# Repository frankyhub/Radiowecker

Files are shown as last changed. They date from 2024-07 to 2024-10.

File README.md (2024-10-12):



<div align="center">

|[:skull:ISSUE](https://github.com/frankyhub/Radiowecker/issues?q=is%3Aissue)|[:speech_balloon: Forum /Discussion](https://github.com/frankyhub/Radiowecker/discussions)|[:grey_question:WiKi](https://github.com/frankyhub/Radiowecker/wiki)||
|--|--|--|--|
| | | | |
||<a href="https://github.com/frankyhub/Radiowecker/issues">|<a href="https://github.com/frankyhub/Radiowecker/discussions">|<a href="https://github.com/frankyhub/Radiowecker/releases">|
|| <a href="https://github.com/frankyhub/Radiowecker/pulse" alt="Activity">| <a href="https://github.com/frankyhub/Radiowecker/graphs/traffic">  |<a href="https://github.com/frankyhub?tab=stars"> |
</div>

Nach einer Idee und Vorlage von https://www.az-delivery.de/blogs/azdelivery-blog-fur-arduino-und-raspberry-pi/internet-radiowecker-mit-touchscreen.

# Radiowecker
Bedienung über 2,8" Touchscreen und WEB-Server, 3W Klasse D Amplifier

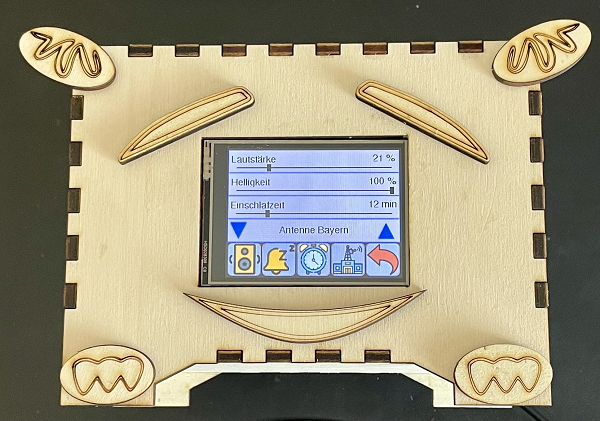
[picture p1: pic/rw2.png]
 

## Story
Das Repo beschreibt einen Radiowecker mit TFT-Display und WEB-Server. Zwei Weckzeiten können an beliebigen Wochentagen zugeordnet werden. Es ist auch ein Einschlaf-Timer vorhanden. Mit dem LDR kann man die Display-Helligkeit automatisch an die Raumhelligkeit anpassen. Über den Touchscreen sind Radio ein/aus, Einschlaftimer mit Einschlafzeit, Wecker ein/aus, Senderauswahl und Lautstärke einstellbar. Die Weckzeiten und die Stream-URLs der Radiostationen werden über ein Web-Interface konfiguriert.

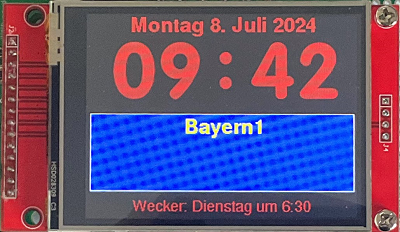
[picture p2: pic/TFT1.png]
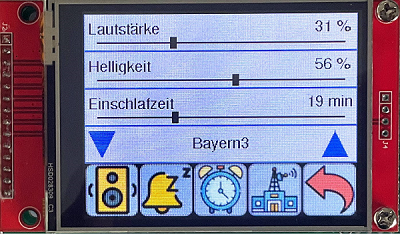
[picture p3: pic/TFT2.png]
 

## Inbetriebnahme

### Verdrahtung 

| TFT-Display | ESP32 | 
| --- | --- |
|  VCC  |  3,3V  |
|  GND | GDN |
| CS  | GPIO5  |
| RESET  | GPIO22 |
| DC | NC  |
| SDI  | GPIO23 |
| SCK  |  GPIO18  |
|  LED |  GPIO15  |
|  MISO | GPIO19 | 
| T-CLK  | GPIO18 | 
| T-CS  | GPIO14  | 
| T-DIN  | GPIO23  | 
| T-DO  | GPIO19  | 
| T-IRQ  | GPIO27  | 
|  --- |  --- | 

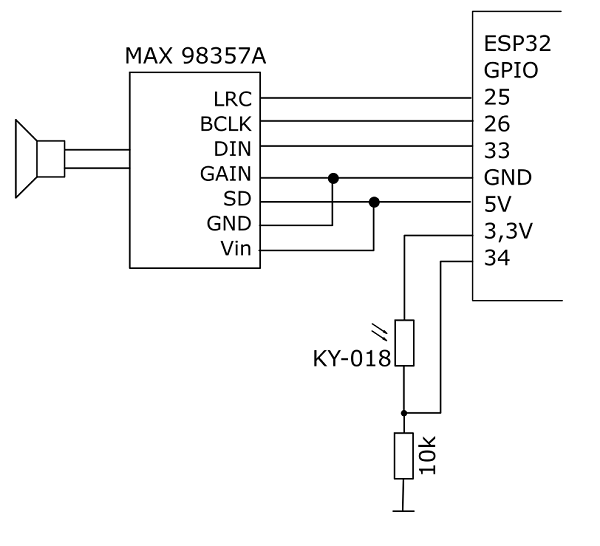
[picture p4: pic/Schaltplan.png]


### ESP32 TFT 2.8" Shield

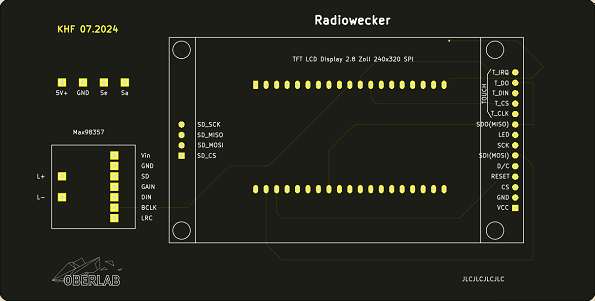
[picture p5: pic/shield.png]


### Gehäuse

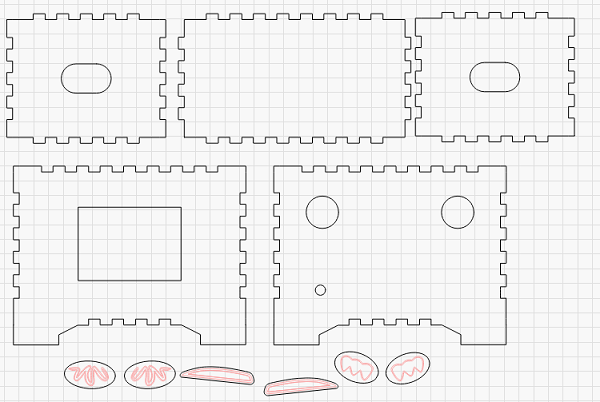
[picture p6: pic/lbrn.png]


### Nach anlegen der Versorgungsspannung startet der Accesspoit. In den Einstellungen des Handys oder Tablets wird das WLAN "Radiowecker" ausgewählt 

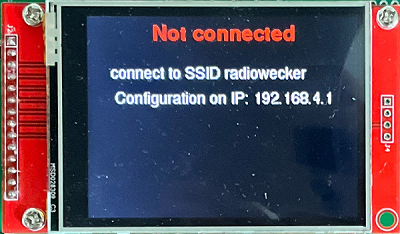
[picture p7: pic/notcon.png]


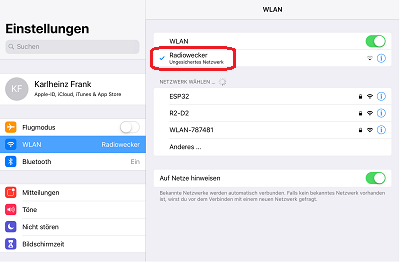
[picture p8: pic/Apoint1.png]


### und über einen Browser die URL 192.168.4.1 eingegeben und der Neustart-Button betätigt.

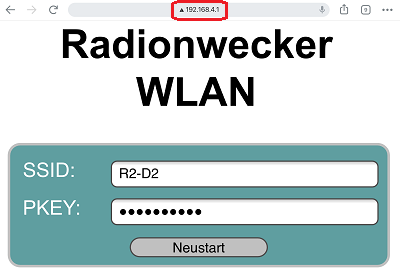
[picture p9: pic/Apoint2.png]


### Am Seriellen Monitor kann der Startvorgang beobachtet und die IP-Adresse des WEB-Servers abgelesen werden.

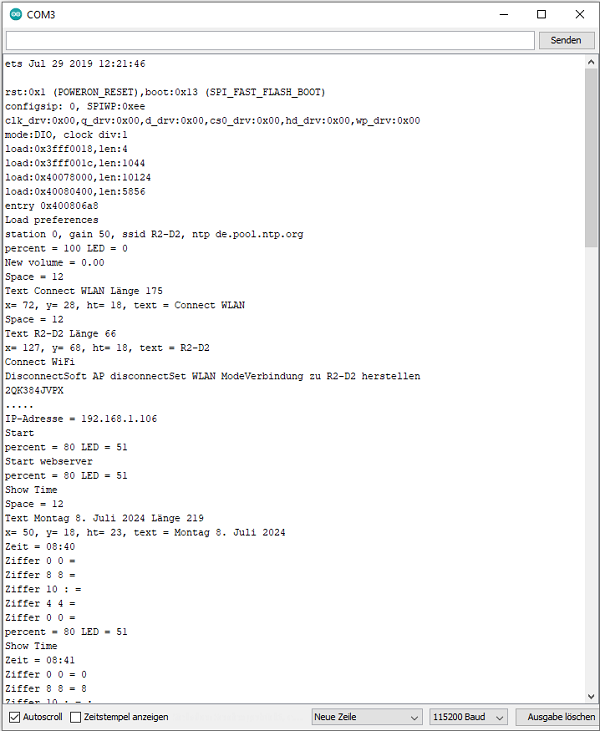
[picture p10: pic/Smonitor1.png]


### Am Display wird beim Startvorgang die WLAN-Verbindung angezeigt.

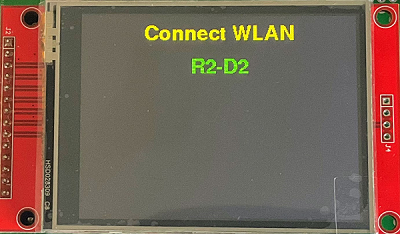
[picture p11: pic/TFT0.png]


### Nach dem Aufruf des WEB-Server sieht man die Einstellungen und passt diese an.

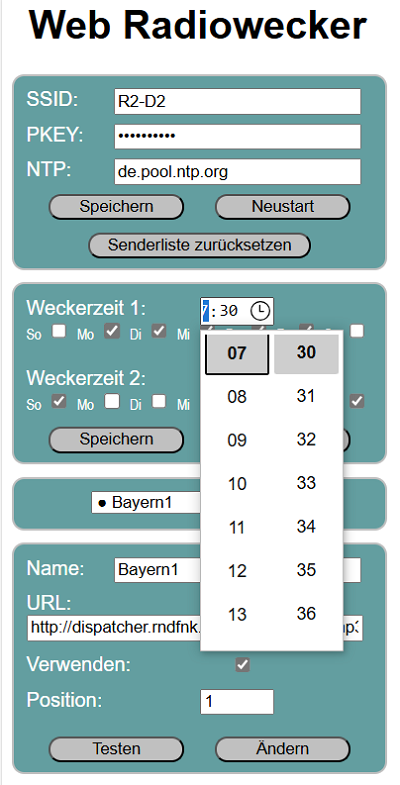
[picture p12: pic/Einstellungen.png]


### Die Bedienung kann auch über das TFT-Display erfolgen.

Bild

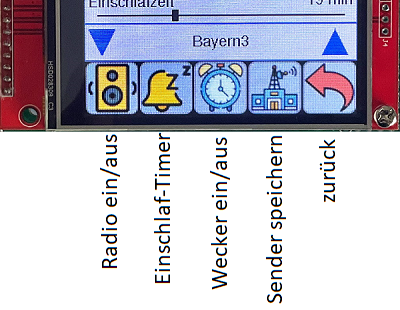
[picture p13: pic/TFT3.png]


## Bedienung

### Radio ein/aus
Das Radio wird ein- oder ausgeschaltet. Die Anzeige kehrt zur Zeitanzeige zurück. Wurde das Radio eingeschaltet, erscheint unter der Zeitanzeige der Radioblock mit dem Sendernamen.

### Einschlaftimer
Die Einschlafzeit wird gestartet. Falls das Radio nicht eingeschaltet ist, wird es eingeschaltet. Die Anzeige kehrt zur Zeitanzeige zurück. Wenn die eingestellte Einschlafzeit vorüber ist, wird das Radio automatisch ausgeschaltet.

### Wecker ein/aus
Die Wecker-Funktion wird ein- oder ausgeschaltet. Die Anzeige kehrt zur Zeitanzeige zurück. Wurde der Wecker eingeschaltet, erscheint ganz unten im Display der Wochentag und die Uhrzeit, wann der Wecker das nächste Mal ausgelöst wird. Wenn der angezeigte Wochentag und die Uhrzeit zutreffen, wird das Radio automatisch eingeschaltet.

### Sender speichern
Der ausgewählte Sender wird als aktiver Sender übernommen. Ist das Radio gerade eingeschaltet, so wechselt der Stream automatisch auf den neuen Sender. Die Anzeige kehrt zur Zeitanzeige zurück.

### Zurück
Die Anzeige kehrt zur Zeitanzeige zurück.

Erfolgt 10 Sekunden keine Aktivität, so kehrt die Anzeige automatisch zur Zeitanzeige zurück. Alle Einstellungsänderungen werden in den Präferenzen gespeichert. Die Bedienungsseite wird immer mit voller Helligkeit dargestellt.

Bild

## Konfiguration

### Über die URL http://radiowecker/ sollte die Konfigurationsseite abrufbar sein. 

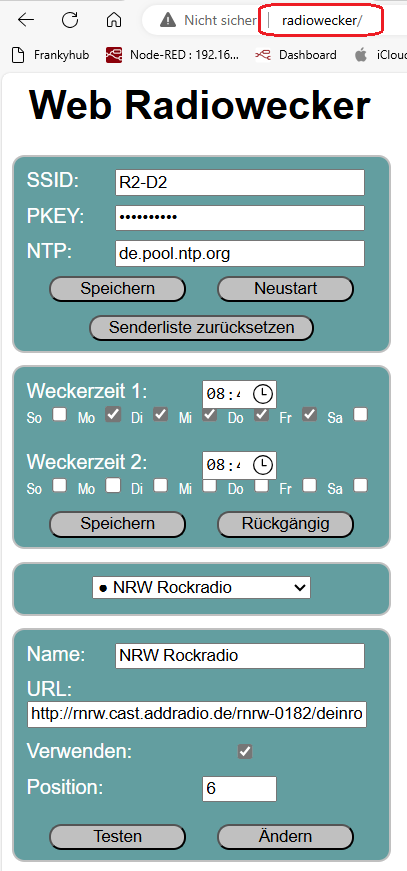
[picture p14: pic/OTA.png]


Im oberen Teil sieht man die WLAN-Zugangsdaten und den NTP-Server. Mit dem "Speichern-Button" werden Änderungen wirksam. Auch ein Neustart ist möglich. Als Nächstes folgen die Weckzeiten. Zwei Weckzeiten sind möglich. Für jede der Weckzeiten sind die Wochentage wählbar, an denen die Weckzeiten anzuwenden sind. Die Dropdown-Liste darunter enthält alle Sender der Senderliste. Auswählbare Sender haben vor dem Namen einen schwarzen Punkt. Im Formular darunter werden die Daten zur ausgewählten Station angezeigt und können geändert werden. Ist das Häkchen bei „Verwenden“ nicht gesetzt, ist die Station im Gerät nicht aktiv. Da manche URLs nicht funktionieren, sollte man eine neue URL erstmal testen. Ein Klicken auf den "Testen-Button" startet die Wiedergabe der URL am eingeschalteten Gerät. Sollte die Wiedergabe nicht funktionieren, wird wieder auf den aktuellen Sender zurückgeschaltet und eine Meldung angezeigt. Ist die Wiedergabe möglich, wird eine Box mit einem Knopf angezeigt. Klicken auf diesen Knopf schließt die Box und beendet den Test. Es wird wieder die aktuelle Station wiedergegeben. Im Eingabefeld „Position“ wird die Position der ausgewählten Station innerhalb der Senderliste angezeigt. Durch eine Änderung dieses Wertes, kann die Station auf die angegebene Position verschoben und mit dem Knopf „Ändern“ können die Änderungen für die ausgewählte Station dauerhaft geändert werden.

---

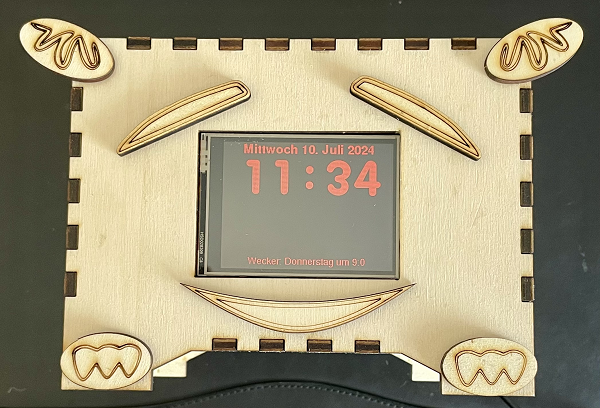
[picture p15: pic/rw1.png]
 

---

<div style="position:absolute; left:2cm; "> <ol class="breadcrumb" style="border-top: 2px solid black;border-bottom:2px solid black; height: 45px; width: 900px;"> <p align="center"><a href="#oben">nach oben</a></p></ol>
</div>  

---

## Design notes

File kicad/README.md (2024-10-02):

ESP32-TFT2.8 Platine

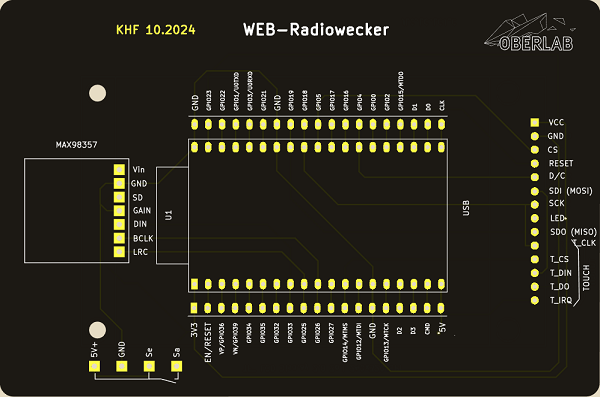
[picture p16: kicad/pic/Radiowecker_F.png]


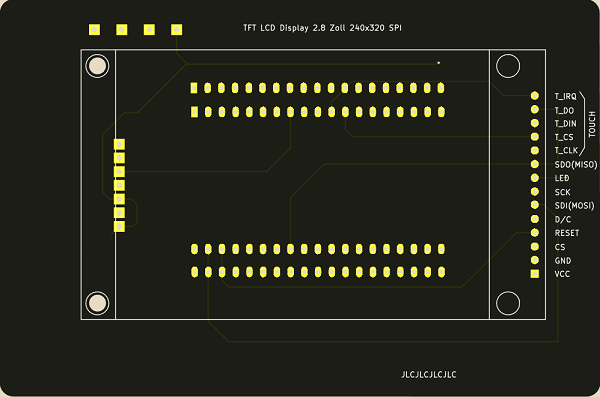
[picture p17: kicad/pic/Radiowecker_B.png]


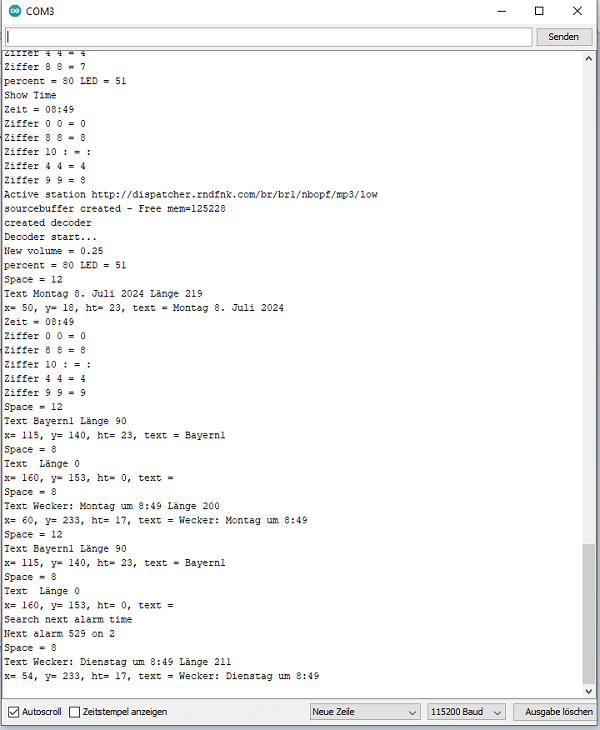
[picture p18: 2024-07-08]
pic/Smonitor2.png

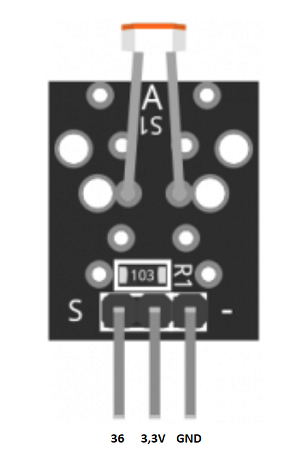
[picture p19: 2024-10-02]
pic/LDR.png

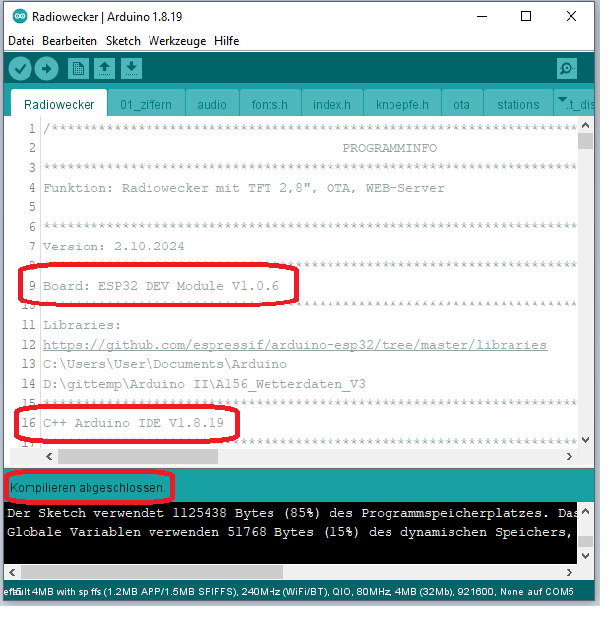
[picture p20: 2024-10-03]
pic/kompile.png

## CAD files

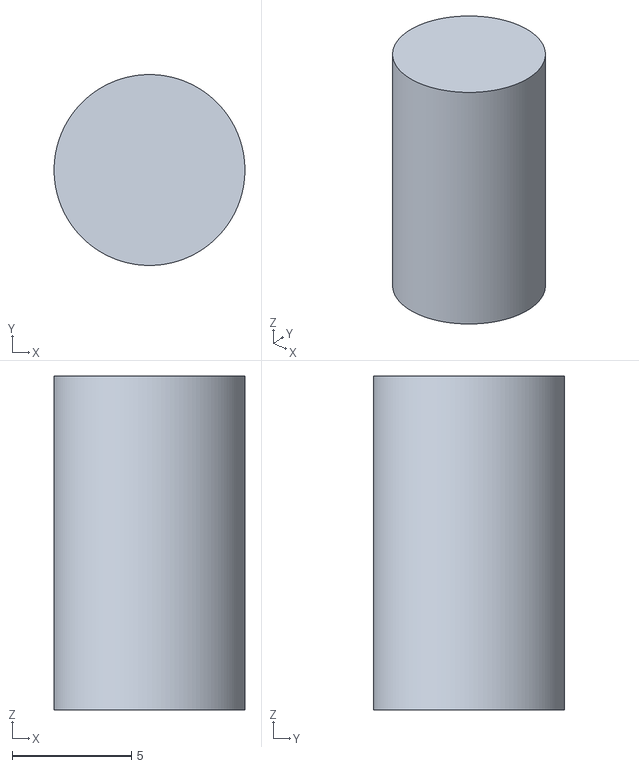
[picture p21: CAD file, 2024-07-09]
3D/PIN14mm.stl
8.00 x 8.00 x 14.0

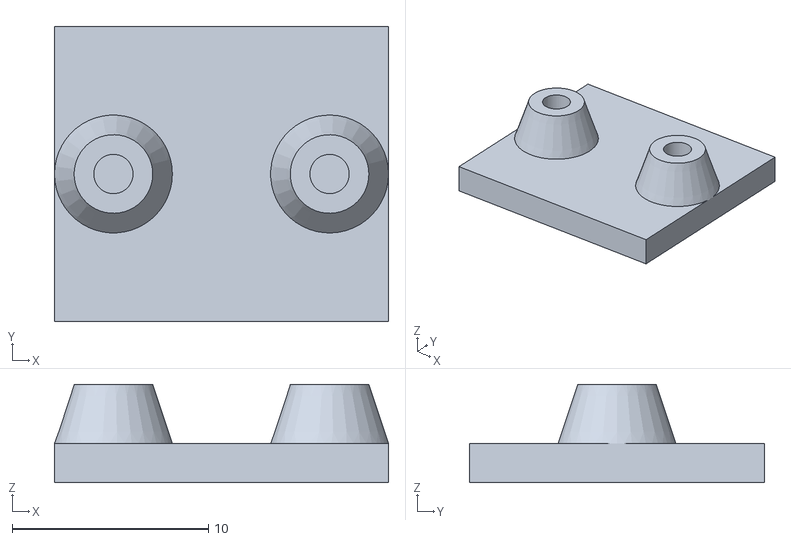
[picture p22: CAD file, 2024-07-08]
3D/LDR.stl
17.0 x 15.0 x 5.00

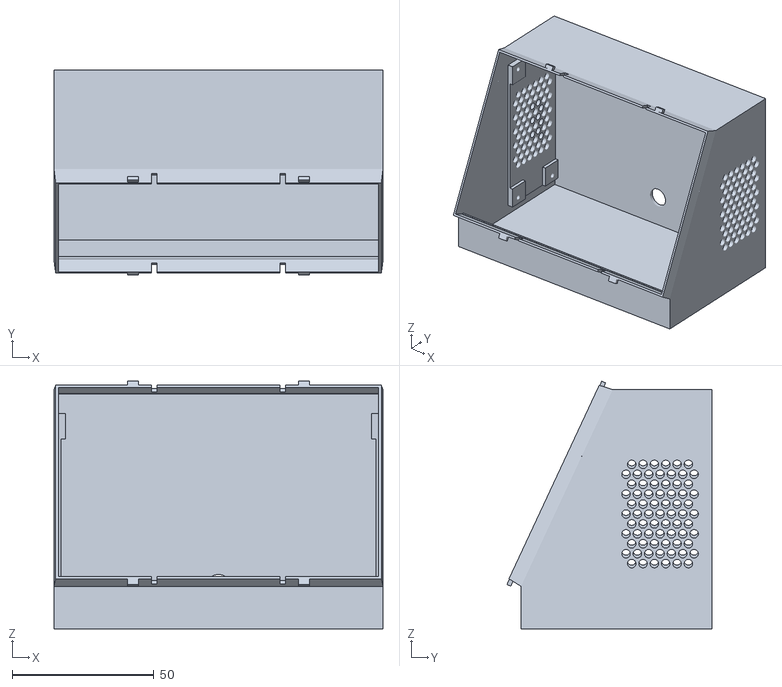
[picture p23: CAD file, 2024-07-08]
3D/PultGehaeuse.stl
116.0 x 72.3 x 87.4

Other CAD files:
3D/PIN14mm.scad

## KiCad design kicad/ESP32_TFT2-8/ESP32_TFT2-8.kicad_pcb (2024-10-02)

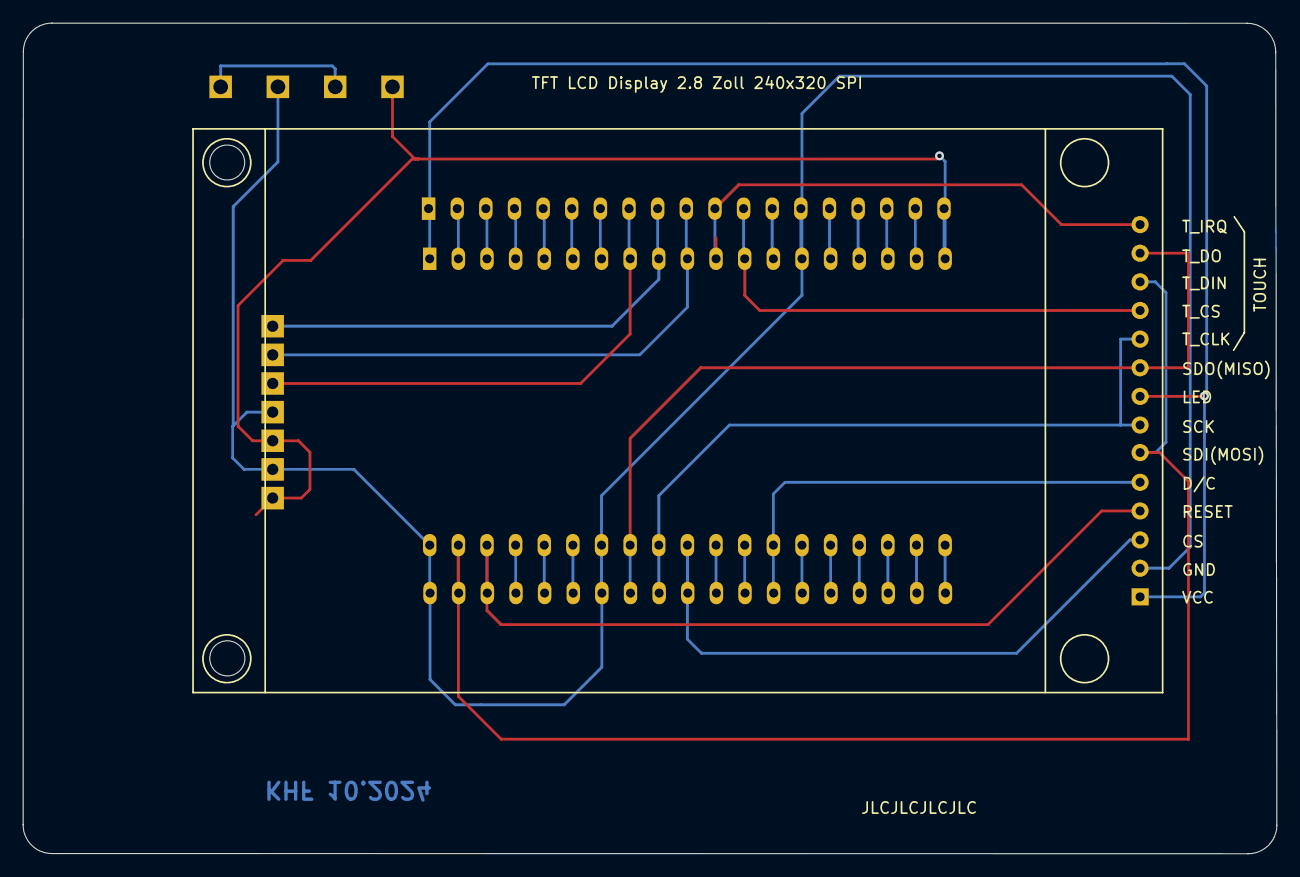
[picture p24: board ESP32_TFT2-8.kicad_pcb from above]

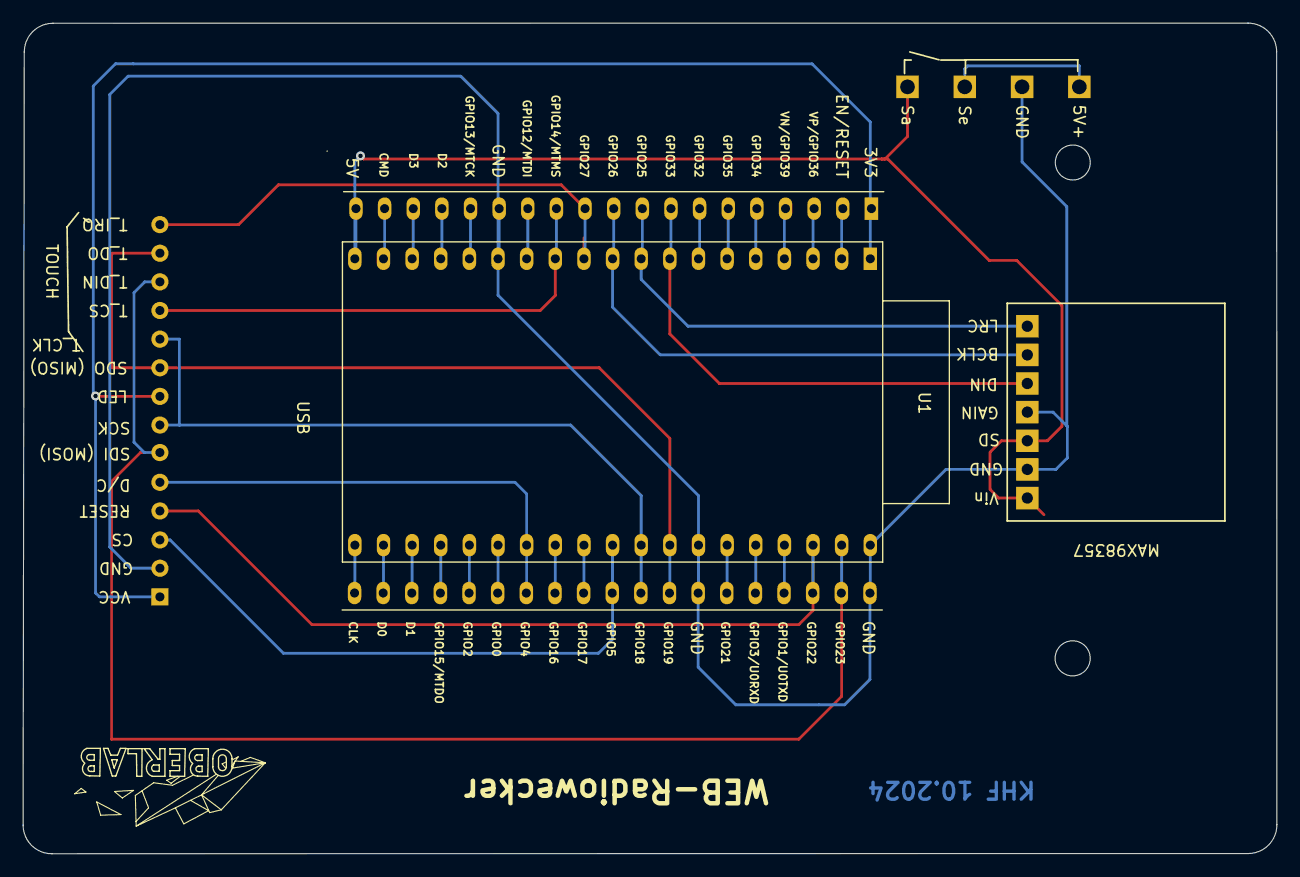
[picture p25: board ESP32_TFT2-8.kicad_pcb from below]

Board: 2 copper layers, 111.2 x 73.7 mm, 13 parts (8 on the bottom side), 14 nets.

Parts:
U1: ESP32-DevKitC
U2: 2.8_tft_240x320_touch_sd_spi
U3: 5V+; LP
U4, U8: GND; LP
U5: Se; LP
U6: Sa; LP
U7: Vin; LP
U9: SD; LP
U10: GAIN; LP
U11: DIN; LP
U12: BCLK; LP
U13: LRC; LP

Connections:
unnamed: U1.1 (3V3), U2.1 (VCC), U2.8 (LED)
unnamed: U1.19 (5V), U6.1 (LP), U7.1 (LP), U9.1 (LP)
unnamed: U1.8 (32K_XN/GPIO33/ADC1_CH5), U11.1 (LP)
unnamed: U1.11 (ADC2_CH7/GPIO27), U2.14 (T_IRQ)
unnamed: U1.9 (DAC_1/ADC2_CH8/GPIO25), U13.1 (LP)
unnamed: U1.10 (DAC_2/ADC2_CH9/GPIO26), U12.1 (LP)
unnamed: U1.29 (GPIO5), U2.3 (CS)
unnamed: U1.30 (GPIO18), U2.7 (SCK), U2.10 (T_CLK)
unnamed: U1.31 (GPIO19), U2.9 (MISO), U2.13 (T_DQ)
unnamed: U1.36 (GPIO22), U2.4 (RESET)
unnamed: U1.37 (GPIO23), U2.6 (MOSI), U2.12 (T_DIN)
unnamed: U1.12 (MTMS/GPIO14/ADC2_CH6), U2.11 (T_CS)
unnamed: U3.1 (LP), U5.1 (LP)
unnamed: U1.14 (GND), U1.32 (GND), U1.38 (GND), U2.2 (GND), U4.1 (LP), U8.1 (LP), U10.1 (LP)

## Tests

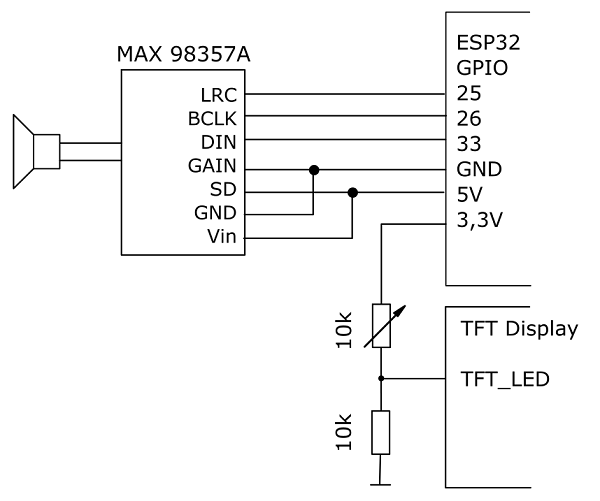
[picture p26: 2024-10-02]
pic/LDR-Test1.png

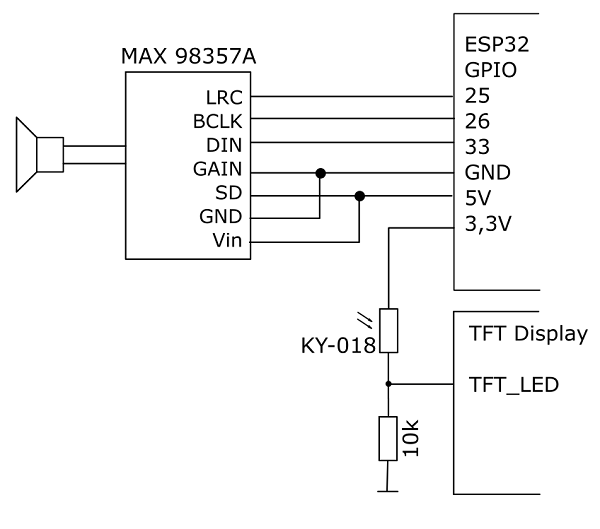
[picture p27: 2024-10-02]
pic/LDR-Test2.png

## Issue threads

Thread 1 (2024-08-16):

Ursprung nicht gekennzeichnet

beabel, 2024-08-16:
Hallo, leider hast du keinen einzigen Verweis auf den Ursprung des Codes bzw Projektes.
Dies macht den Anschein, das es von dir stammt!
Jedoch ist der Original Code  / Projekt von Az-Delivery. Wäre nett wenn dies erwähnt würde.
MfG

frankyhub, 2024-08-17:
——————————————Frank Karlheinz Fachbereichsleiter Elektronik Fablab Tölzer Straße 3a83703 Gmund am ***@***.***/55538286oberlab.deAm 17.08.2024 um 00:04 schrieb kunigunde ***@***.***>:
Hallo, leider hast du keinen einzigen Verweis auf den Ursprung des Codes bzw Projektes.
Dies macht den Anschein, das es von dir stammt!
Jedoch ist der Original Code  / Projekt von Az-Delivery. Wäre nett wenn dies erwähnt würde.
MfG

—Reply to this email directly, view it on GitHub, or unsubscribe.You are receiving this because you are subscribed to this thread.Message ID: ***@***.***>

frankyhub, 2024-08-17:
Danke für den Hinweis, das mache ich natürlich.

Closed 2024-08-17.

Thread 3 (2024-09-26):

LDR's work

samand587, 2024-09-26:
0 means use LDR to control brightness. Why doesn't he want to work?

frankyhub, 2024-09-26:
hi, I'm not at home at the moment and can't check the problem. I'll write to you when I get back. please be patient.

samand587, 2024-09-27:
How do I set my time zone?

samand587, 2024-09-27:
Switched to radiowecker version 3.0.5- LDR does not work

frankyhub, 2024-10-02:
Please look at wiki:

https://github.com/frankyhub/Radiowecker/wiki/Radiowecker-wiki

samand587, 2024-10-02:
Hallo! Ich habe alles gemäß den Empfehlungen eingerichtet, aber der Sensor funktioniert nicht. Was kann ich sonst noch in der Skizze sehen?

frankyhub, 2024-10-02:
Was sagt der Serielle Monitor?
Programmzeile 245
Serial.printf("ldr %i letzter %i\n",tmp,lastldr);

samand587, 2024-10-02:
Ich habe jetzt Version 3.0.5. In Ihrer Zeile 245 steht geschrieben   Serial.printf("ldr %i letzter %i\n",tmp,lastldr);
Hafen-Monitor: ets Jul 29 2019 12:21:46
rst:0x1 (POWERON_RESET),boot:0x13 (SPI_FAST_FLASH_BOOT)
configsip: 0, SPIWP:0xee
clk_drv:0x00,q_drv:0x00,d_drv:0x00,cs0_drv:0x00,hd_drv:0x00,wp_drv:0x00
mode:DIO, clock div:1
load:0x3fff0030,len:1344
load:0x40078000,len:13924
ho 0 tail 12 room 4
load:0x40080400,len:3600
entry 0x400805f0
Load preferences
station 3, gain 16, ssid dlink, ntp de.pool.ntp.org
percent = 100 LED = 0
New volume = 0.00
Connect WiFi
DisconnectSoft AP disconnectSet WLAN ModeVerbindung zu dlink herstellen
123asdzxc
.
IP-Adresse = 192.168.0.108
Start
percent = 80 LED = 51
Zeit = 16:20
Start webserver
percent = 80 LED = 51
Show Time
Zeit = 16:21
percent = 80 LED = 51
Show Time
Zeit = 16:22

frankyhub, 2024-10-02:
Teste mal den LDR:

Test 1
[Bild](https://github.com/frankyhub/Radiowecker/blob/main/pic/LDR-Test1.png)

Test 2
[Bild](https://github.com/frankyhub/Radiowecker/blob/main/pic/LDR-Test2.png)

samand587, 2024-10-02:
Angeschlossen an Test 2, LDR ist in Ordnung, reagiert auf die Beleuchtung

frankyhub, 2024-10-02:
Wenn Test 2 funktioniert, kannst du ja die Helligkeit des TFT-Displays direkt über den LDR steuern.

samand587, 2024-10-02:
Mit dem Test 2 gibt es scharfe Lichtsprünge des Displays. Warum will er nicht so arbeiten, wie es in der Skizze steht? Ich möchte dieses Problem lösen!

frankyhub, 2024-10-02:
Mit der Version 1.2.4 ist das Problem gelöst.
Änderung:

#define LDR 34
#define TFT_LED  15

//  analogWrite(TFT_LED, ledb); ->
analogWrite(TFT_LED, ledb)

samand587, 2024-10-03:
Hallo! Ich habe zu pin 34 gewechselt, der Rest funktioniert wie oben geschrieben - LDR funktioniert nicht.  Als nächstes weiß ich nicht, was ich tun soll?!

frankyhub, 2024-10-03:
Hallo, TFT_LED auf GPIO15.

samand587, 2024-10-03:
Ja, ich habe TFT_LED auf GPIO15. Funktioniert aber nicht.

frankyhub, 2024-10-03:
und die Version 1.2.4 in den ESP laden.

samand587, 2024-10-03:
" version 1.2.4 in ESP." Was ist hier gemeint?

frankyhub, 2024-10-03:
Lade das Repo down, kompiliere das Programm und lade dann die Radiowecker.ino in den ESP32. Dann funktioniert der LDR. Du kannst die Änderung der Lichtwerte auch im Seriellen Monitor sehen.

samand587, 2024-10-03:
Es wird ein Fehler ausgegeben:

C:\Users\User\Documents\Arduino\libraries\ESP32_AnalogWrite-master\src\analogWrite.cpp:47:9: note: suggested alternative: 'ledcAttachPin'

         ledcAttach(pin, _analog_write_channels[i].frequency, _analog_write_channels[i].resolution);

         ^~~~~~~~~~

         ledcAttachPin

frankyhub, 2024-10-03:
Arduino IDE, Board: ESP32 DEV Module V1.0.6?

frankyhub, 2024-10-07:
ok

frankyhub, 2024-10-07:
ok

Closed 2024-10-07.

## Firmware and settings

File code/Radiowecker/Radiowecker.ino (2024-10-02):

/*************************************************************************************************
                                      PROGRAMMINFO
**************************************************************************************************
Funktion: Radiowecker mit TFT 2,8", OTA, WEB-Server

**************************************************************************************************
Version: 2.10.2024
**************************************************************************************************
Board: ESP32 DEV Module
**************************************************************************************************
Libraries:
https://github.com/espressif/arduino-esp32/tree/master/libraries
C:\Users\User\Documents\Arduino
D:\gittemp\Arduino II\A156_Wetterdaten_V3
**************************************************************************************************
C++ Arduino IDE V1.8.19
**************************************************************************************************
Einstellungen:
https://dl.espressif.com/dl/package_esp32_index.json
http://dan.drown.org/stm32duino/package_STM32duino_index.json
http://arduino.esp8266.com/stable/package_esp8266com_index.json
**************************************************************************************************/

#include <WiFi.h> 
#include <ArduinoOTA.h>
#include "knoepfe.h" //Graphic data for buttons
#include "Adafruit_ILI9341.h" //Display driver
#include <XPT2046_Touchscreen.h> //Touchscreen driver
#include <TouchEvent.h> //Examines touchscreen events


//esp32 library to save preferences in flash
#include <Preferences.h>

//definitions for text output alignment
#define ALIGNLEFT 0
#define ALIGNCENTER 1
#define ALIGNRIGHT 2

//pin to be used for light sensor
#define LDR 34
#define TFT_LED  15

//instance of prefernces
Preferences pref;
Preferences sender;

//structure for station list
typedef struct {
  char url[150];  //stream url
  char name[32];  //stations name
  uint8_t enabled;//flag to activate the station
} Station;

#define STATIONS 19 //number of stations in the list

//gloabal variables
Station stationlist[STATIONS];    //list of available stations
//variables to hold configuration data
String ssid = "";                 //ssid for WLAN connection
String pkey = "";                 //passkey for WLAN connection
String ntp = "de.pool.ntp.org";   //NTP server url
uint8_t curStation = 0;           //index for current selected station in stationlist
uint8_t curGain = 200;            //current loudness
uint8_t snoozeTime = 30;          //snooze time in minutes
uint16_t alarm1 = 390;            //first alarm time 6:30
uint8_t alarmday1 = 0B00111110;   //valid weekdays (example 00111110 means monday through friday)
uint16_t alarm2 = 480;            //second alarm time 8:00
uint8_t alarmday2 = 0B01000001;   //valid week days (example 01000001 means sunday and saturday)
uint8_t actStation = 0;           //index for current station in station list used for streaming 
uint8_t bright = 0;              //brightness in percent. 0 means use LDR to control brightness
//other global variables
uint32_t lastchange = 0;          //time of last selection change
uint8_t snoozeWait = 0;           //remaining minutes fro snooze
uint16_t alarmtime = 0;           //next relevant alarm time
uint8_t alarmday = 8;             //weekday for next relevant alarm or 8 means alarm disabled
char title[64];                   //character array to hold meta data message
bool newTitle = false;            //flag to signal a new title
uint32_t tick = 0;                //last tick-counter value to trigger timed event
uint32_t discon = 0;              //tick-counter value to calculate disconnected time
uint16_t minutes;                 //current number of minutes since midnight
uint8_t weekday;                  //current weekday
struct tm ti;                     //time structure with current time
int16_t lastldr;                  //last value from LDR sensor to detect changes
uint32_t start_conf;              //time of entering config screen
boolean connected;                //flag to signal active connection
boolean radio = false;            //flag to signal radio output
boolean clockmode = true;         //flag to signal clock is shown on the screen

//predefined function from modul tft_display.ino
void displayMessage(uint16_t x, uint16_t y, uint16_t w, uint16_t h, const char* text, uint8_t align = ALIGNLEFT, boolean big = false, uint16_t fc = ILI9341_WHITE , uint16_t bg = ILI9341_BLACK, uint8_t lines = 1 );

//calculate date and time for next expected alarm
//set alarmtime to the time on the day and alarmday on weekday for alarm
//or 8 if no alarm exists
void findNextAlarm() {
  Serial.println("Search next alarm time");
  int wd; 
  uint8_t mask;
  if (getLocalTime(&ti)) { //get current date and time
    wd = weekday; //variable to iterate over weekdays starting with today
    alarmday = 8;  //alarmday = 8 means no alarm
    mask = 1 << wd;  //mask to filter weekday to be tested
    //test if alarm settings 1 matchs
    if ((alarmday == 8) && ((alarmday1 & mask) != 0) && (alarm1 > minutes)) 
      { alarmtime = alarm1; alarmday = wd;}
    //test if alarm settings 2 matchs
    if ((alarmday == 8) && ((alarmday2 & mask) != 0) && (alarm2 > minutes)) 
      { alarmtime = alarm2; alarmday = wd;}
    if (alarmday == 8) { //if no alarm continue search
      do {
        wd++; //next weekday
        if (wd > 7) wd = 0;
        mask = 1 << wd;
        //test if alarm settings 1 matchs
        if ((alarmday == 8) && ((alarmday1 & mask) != 0) ) { alarmtime = alarm1; alarmday = wd;}
        //test if alarm settings 1 matchs
        if ((alarmday == 8) && ((alarmday2 & mask) != 0) ) { alarmtime = alarm2; alarmday = wd;}
        
      } while ((alarmday == 8) && (wd != weekday)); //continue until an valid alarm was found or a week is over
    }
    
    Serial.printf("Next alarm %i on %i\n",alarmtime,alarmday);
  }
}

//setup
void setup() {

  pinMode(TFT_LED,OUTPUT);
  pinMode(LDR,INPUT);
  
  Serial.begin(115200);
  Serial.println("Load preferences");
  title[0] = 0;
  //preferences will be saved in the EPROM of the ESP32 to keep the values 
  //when power supply will be interrupted
  //Two topics "radio" and "senderliste" are defined. We will mount both
  pref.begin("radio", false);
  sender.begin("senderlist",false);
  //get values from preferences
  if (pref.isKey("ssid")) ssid = pref.getString("ssid");
  if (pref.isKey("pkey")) pkey = pref.getString("pkey");
  if (pref.isKey("ntp")) ntp = pref.getString("ntp");
  curGain = 50; //default value
  if (pref.isKey("gain")) curGain = pref.getUShort("gain");
  snoozeTime = 30; //default value
  if (pref.isKey("snooze")) snoozeTime = pref.getUShort("snooze");
  bright = 0; //default value
  if (pref.isKey("bright")) bright = pref.getUShort("bright");
  alarm1 = 390;    //6:30
  if (pref.isKey("alarm1")) alarm1 = pref.getUInt("alarm1");
  alarmday1 = 0B00111110; //mo-fr
  if (pref.isKey("alarmday1")) alarmday1 = pref.getUShort("alarmday1");
  alarm2 = 480;    //8:00
  if (pref.isKey("alarm2")) alarm2 = pref.getUInt("alarm2");
  alarmday2 = 0B01000001; //so,sa
  if (pref.isKey("alarmday2")) alarmday2 = pref.getUShort("alarmday2");
  alarmtime = 0;
  alarmday = 8; //alarm is off
  curStation = 0; //default value
  //set current station to saved value if available
  if (pref.isKey("station")) curStation = pref.getUShort("station");
  if (curStation >= STATIONS) curStation = 0; //check to avoid invalid station number
  actStation = curStation;   //set active station to current station 
  Serial.printf("station %i, gain %i, ssid %s, ntp %s\n", curStation, curGain, ssid.c_str(), ntp.c_str());
  //run setup functions in the sub parts
  setup_audio(); //setup audio streams
  setup_display(); //setup display interface
  setup_senderList(); //load station list from preferences
  setGain(0); //set the current gain
  //Try to connect WLAN show progress on display 
  displayClear();
  displayMessage(5, 10, 310, 30, "Connect WLAN", ALIGNCENTER, true, ILI9341_YELLOW, ILI9341_BLACK,1);
  displayMessage(5, 50, 310, 30, ssid.c_str(), ALIGNCENTER, true, ILI9341_GREEN, ILI9341_BLACK,1);
  Serial.println("Connect WiFi");
  connected = initWiFi(ssid, pkey);
  if (connected) { //successful connection
    //setup real time clock
    configTzTime("CET-1CEST,M3.5.0/03,M10.5.0/03", ntp.c_str());
    //show date and time and the name of the station
    delay(500);
    //fill timestarukture ti, minutes and weekday with now
    getLocalTime(&ti);
    minutes = ti.tm_hour * 60 + ti.tm_min;
    weekday = ti.tm_wday;
    Serial.println("Start");
    //if alarm is on get date and time for next alarm
    if (pref.isKey("alarmon") && pref.getBool("alarmon")) findNextAlarm();
    //Display time and next alarm if one is set
    showClock();
  } else { //connection not successful
    //we have no connection. A message will be shown on the display
    displayClear();
    displayMessage(5, 10, 310, 30, "Not connected", ALIGNCENTER, true, ILI9341_RED, ILI9341_BLACK,1);
    displayMessage(5, 60, 310, 30, "connect to SSID radioweckerconf", ALIGNCENTER, false, ILI9341_WHITE, ILI9341_BLACK,1);
    displayMessage(5, 90, 310, 30, "Configuration on IP: 192.168.4.1", ALIGNCENTER, false, ILI9341_WHITE, ILI9341_BLACK,1);
    //remember current tick count to allow
    //a retry after five minutes disconnected
    discon = millis();
  }
  Serial.println("Start webserver");
  //setup the web server and the over the air update
  setup_webserver();
  setup_ota();
  //remember the tick count for the timed event
  tick = millis();
  start_conf = 0;
}


void loop() {
  //Check over the air update
  ArduinoOTA.handle();
  //Check for http requests
  webserver_loop();
  //check for touch events
  touch_loop();
  //after 10 seconds switch back from config screen to clock screen
  if (!clockmode && ((millis() - start_conf) > 10000)) {
    showClock();
    clockmode = true;
  }
  //show metadata if radio is active
  if (newTitle && radio && clockmode) {
    showTitle();
    newTitle = false;
  }
  //detect a disconnect
  if (connected && (WiFi.status() != WL_CONNECTED)){
    connected = false;
    //remember tick count for automatic retry
    discon = millis();
    //show message on display
    displayClear();
    displayMessage(5, 10, 310, 30, "Connection lost", ALIGNCENTER, true, ILI9341_RED, ILI9341_BLACK,1);
  }
  //if radio is on get new stream data
  if (connected && radio) {
    audio_loop();
  }
  //if brightness is set to 0, brightness will be controlled by ambient light
  if (bright == 0) {
    int16_t tmp = analogRead(LDR);
    int16_t diff = lastldr - tmp;
    diff = abs(diff);
    //set BG light if clock is displayed
    if (clockmode && (diff > 50)) {
      setBGLight(bright);
      Serial.printf("ldr %i letzter %i\n",tmp,lastldr);
      //remember current ambient light to detect changes
      lastldr = tmp;
    }
  } 
  //timed event updatetime display every minute  
  if ((millis() - tick) > 60000) {
    tick = millis();
    //get date and time information
    if (connected  && getLocalTime(&ti)) {
      minutes = ti.tm_hour * 60 + ti.tm_min;
      weekday = ti.tm_wday;
    } else {
      connected = false;
      discon = millis();
    }
    //set BG light if clockk is displayed
    if (connected && clockmode) {
      setBGLight(bright);
      displayDateTime();
    }
    //if we are in snooze mode decrement snooze counter
    //and turn radio off if snooze counter is zero
    if (snoozeWait > 0) {
      snoozeWait--;
      if (snoozeWait == 0) {
        toggleRadio(true);
        showRadio();
      }
      
    }
    //if an alarm is activated check for day and time
    if ((alarmday < 8) && getLocalTime(&ti)) {
      //if alarm day and time is reached turn radio on and get values for next expected alarm
      if ((alarmday == weekday) && ((minutes == alarmtime) || (minutes == (alarmtime+1)))) {
        toggleRadio(false);
        showRadio();
        findNextAlarm();
        showNextAlarm();
      }
    }

  }
  //do a restart if device was disconnected for more then 5 minutes
  if (!connected && ((millis() - discon) > 300000)) ESP.restart();
}

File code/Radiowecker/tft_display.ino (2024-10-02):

#include "Adafruit_GFX.h"
#include "Adafruit_ILI9341.h"
#include "fonts.h"
#include <analogWrite.h>
//pins for touchscreen
#define TOUCH_CS 14
#define TOUCH_IRQ 27

//define names for fonts
#define FNT9 &AT_Standard9pt7b
#define FNT12 &AT_Bold12pt7b

//pins for display
#define TFT_CS   5   
#define TFT_DC   4   
#define TFT_RST  22
#define TFT_LED  15
#define TOUCH_CS 14
#define LED_ON 0
#define LS 23  // line spacing

//day and month names in German
const char* const PROGMEM days[] = {"Sonntag","Montag","Dienstag","Mittwoch","Donnerstag","Freitag","Samstag"};
const char* PROGMEM months[] = {"Jan.","Feb.","Maerz","April","Mai","Juni","Juli","Aug.","Sept.","Okt.","Nov.","Dez."};

//instance of display driver
Adafruit_ILI9341 tft = Adafruit_ILI9341(TFT_CS, TFT_DC, TFT_RST);
//instance for touchscreen driver
XPT2046_Touchscreen touch(TOUCH_CS, TOUCH_IRQ);
//instance to start callbacks on touch events
TouchEvent tevent(touch);

//register a callback for any touch event.
//we get position and type of the event
void onTouchClick(TS_Point p) {
  if (!clockmode) start_conf = millis(); //if we are in config mode reset start_conf on any event
  Serial.printf("Touch on %i, %i\n",p.x,p.y);
  if (clockmode) { //if we are in the clock mode, we switch into the config mode. Independent where the event occured.
    clockmode = false;
    showCommand(); 
  } else {
    //we are in the config mode
    if (p.y > 180) { //if the y value > 180, we are in the button area
      //we nned the p.x position to find which button was clicked
      if (p.x < 64) toggleRadio(radio);
      if ((p.x>64) && (p.x<128)) startSnooze();
      if ((p.x>128) && (p.x<192)) toggleAlarm();
      if ((p.x>192) && (p.x<256)) changeStation();
      if (p.x > 256) {
        clockmode = true;
        showClock();
      }
    }
    //from 0 to 44 we have the slider for gain
    if ((p.y > 0) && (p.y<44)) setGainValue(p.x);
    //from 44 to 88 we have the slider for brightness
    if ((p.y > 44) && (p.y<88)) setBrightness(p.x);
    //from 88 to 132 we have the slider for snooze time
    if ((p.y > 88) && (p.y<132)) setSnoozeTime(p.x);
    //from 132 to 175 we have the station list
    if ((p.y > 132) && (p.y<175)) selectStation(p.x);
  }
}

//set the gain for x-position where the slider was clicked
void setGainValue(uint16_t value) {
  char txt[10];
  //calculate gain from x-Position 0 to 100%
  float v = (value - 15) * 0.345;
  if (v > 100) v = 100;
  if (v < 0) v = 0;
  curGain = v;
  //save gain and adjust slider and set gain to the new value
  pref.putUShort("gain",curGain);
  showSlider(27,curGain,100);
  setGain(curGain);
  sprintf(txt,"%i %%",curGain);
  displayMessage(231,8,80,20,txt,ALIGNRIGHT,false,ILI9341_BLACK,ILI9341_LIGHTGREY,1);
}

//set the brightness for x-position where the slider was clicked
void setBrightness(uint16_t value) {
  char txt[10];
  //calculate brightness from x-Position 0 to 100 %
  float v = (value - 15) * 0.345;
  if (v > 100) v = 100;
  if (v < 5) v = 0;
  bright = v;
  //save brightness and adjust slider 
  pref.putUShort("bright",bright);
  setBGLight(bright);
  showSlider(71,bright,100);
  sprintf(txt,"%i %%",bright);
  displayMessage(231,52,80,20,txt,ALIGNRIGHT,false,ILI9341_BLACK,ILI9341_LIGHTGREY,1);
}

//set the snooze time for x-position where the slider was clicked
void setSnoozeTime(uint16_t value) {
  char txt[10];
  //calculate snooze time from x-Position 0 to 60 minutes
  float v = (value - 15) * 0.21;
  if (v > 60) v = 60;
  if (v < 0) v = 0;
  snoozeTime = v;
  //save snooze time and adjust slider 
  pref.putUShort("snooze",snoozeTime);
  showSlider(115,snoozeTime,60);
  sprintf(txt,"%i min",snoozeTime);
  displayMessage(231,96,80,20,txt,ALIGNRIGHT,false,ILI9341_BLACK,ILI9341_LIGHTGREY,1);
}

//adjust the brightness of the background led
void setBGLight(uint8_t prct) {
  uint16_t ledb;
  //if brightness is 0, we read the ambient light from LDR
  if (prct == 0) {
    ledb = analogRead(LDR) * 255 /4096;
  } else {
    ledb = 255*prct/100;
  }
  if (ledb > 255) ledb = 255;
  if (ledb <3) ledb = 3; //minimal brightness
  if (LED_ON == 0) ledb = 255 - ledb;
  Serial.printf("percent = %i LED = %i\n",prct,ledb);
  //set the LED
  analogWrite(TFT_LED, ledb);
}

//select a station from the stationlist
void selectStation(uint16_t x) {
  //there are two buttons left and right to scroll through the stationlist
  if (x<50) { //left button to scroll down
    //we go down until we find an enabled station
    do {
      if (curStation == 0) {
        curStation = STATIONS - 1;
      }else {
        curStation --;
      }
    }
    while (! stationlist[curStation].enabled);
  }
  if (x>270) { //left button to scroll up
    //we go up until we find an enabled station
    do {
      if (curStation == (STATIONS - 1)) {
        curStation = 0;
      }else {
        curStation ++;
      }
    }
    while (! stationlist[curStation].enabled);
  }
  //show the selected station
  updateStation();
}

//turn the radio on or off
void toggleRadio(boolean off) {
  if (off) {
    //if off stop the stream
    stopPlaying();
    radio = false;
    //setGain(0);
  } else {
    if (connected) {
      //if on start the stream an set the gain
      radio = true;
      if (!startUrl(String(stationlist[actStation].url))) {
        //if no success switch to station 0
        actStation = 0;
        startUrl(String(stationlist[actStation].url));
      }
      setGain(curGain);
    }
  }
  //switch to clock screen
  clockmode = true;
  showClock();
}

//turn the alarm on or off
void toggleAlarm() {
  if (alarmday > 7) {
    //if the alarm was off find the next alarm an activate it
    findNextAlarm();
    pref.putBool("alarmon",true);
  } else {
    //deactivate the alarm
    alarmday = 8;
    pref.putBool("alarmon",false);
  }
  //switch to clock screen
  clockmode = true;
  showClock();
  }

void startSnooze() {
  snoozeWait = snoozeTime;
  toggleRadio(false);
  clockmode = true;
  showClock();
}

//set the selected station as the active station
void changeStation() {
    actStation = curStation;
    //save the new value and start stream
    pref.putUShort("station",curStation);
    if (!startUrl(String(stationlist[actStation].url))) {
      //if start fails we switch back to station 0
      actStation = 0;
      startUrl(String(stationlist[actStation].url));
    }
  //switch to clock screen
  clockmode = true;
  showClock();
}

//called from the main loop to handle touch events
void touch_loop() {
    tevent.pollTouchScreen();
}

//prepare display
void setup_display() {

  lastldr = analogRead(LDR);
  setBGLight(bright);

  tft.begin();
  tft.setTextColor(ILI9341_WHITE);
  tft.fillScreen(ILI9341_BLACK);
  tft.setRotation(3);
  tft.setFont(&AT_Bold12pt7b);
  touch.begin();
  tevent.setResolution(tft.width(),tft.height());
  tevent.setDrawMode(false);
  //register callback function
  tevent.registerOnTouchClick(onTouchClick);
}
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

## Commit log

2024-07-08 V 08072024
    [LDR.stl, PultGehaeuse.stl]
2024-07-09 V 09072024
    [PIN14mm.scad, PIN14mm.stl]
2024-07-13 V 13072024
    [ESP32_TFT2-8-B_Cu.gbr, ESP32_TFT2-8-B_Mask.gbr, ESP32_TFT2-8-B_Paste.gbr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]
2024-09-10 V 10092024
    [ESP32_TFT2-8-B_Cu.gbr, ESP32_TFT2-8-B_Mask.gbr, ESP32_TFT2-8-B_Paste.gbr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]
2024-10-02 V 02102024
    [ESP32_TFT2-8-B_Cu.gbr, ESP32_TFT2-8-B_Mask.gbr, ESP32_TFT2-8-B_Paste.gbr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]
